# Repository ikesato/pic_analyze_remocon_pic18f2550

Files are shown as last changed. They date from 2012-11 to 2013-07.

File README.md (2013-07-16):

概要
====
家庭用リモコン信号を受信しコードを解析する。  
また解析したコードを送信し解析したコードのテストを可能とする。  

- マイコン : PIC18F2550
- USB接続 (CDC クラスを使用)
- CDC Basic Demo をベースに赤外線LEDの送受信し、データをシリアル通信で送受信
- 赤外通信 38KHz
- 解析できるコードは家電協フォーマット、ソニーフォーマット
- 受信と解析  
 リモコン -> 赤外線受光部 -> マイコン -> PCでコードを解析
- 送信  
 PC -> マイコン -> 赤外LEDで送信
- フリスクケースに収まるサイズで作成

回路図
=====
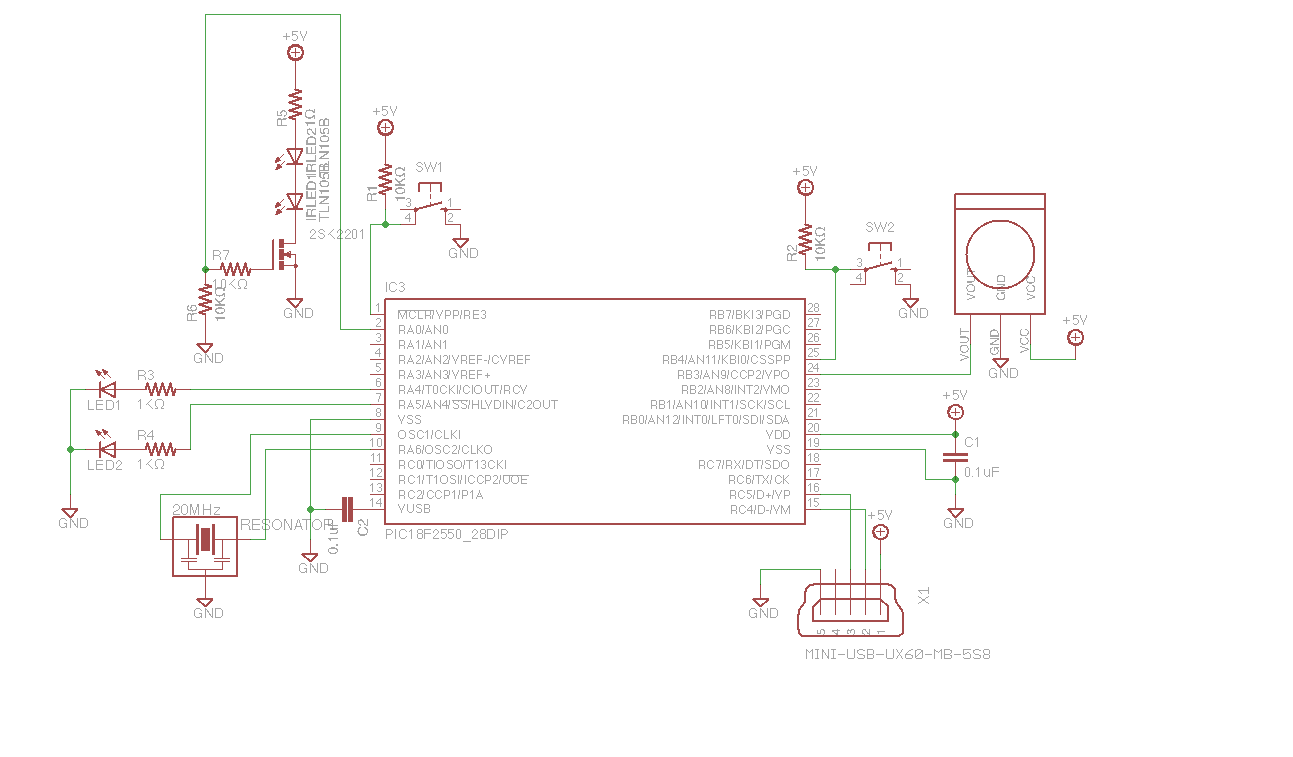
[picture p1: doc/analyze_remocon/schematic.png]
回路図


配線
====
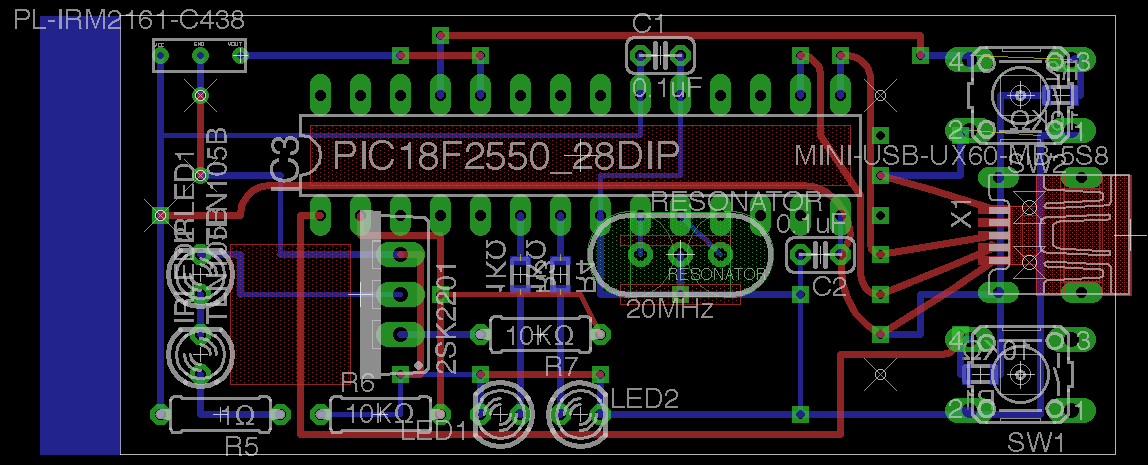
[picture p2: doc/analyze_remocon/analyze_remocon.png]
配線


部品
====
- LED x 2
- 赤外線LED x 2
 型番 : TLN105B
- 赤外線受光モジュール  
 型番 : PL-IRM2161-C438
- FET  
 型番 : 2SK2201
- 水晶振動子 20MHz
- マイコン : PIC18F2550 DIP 28ピン
- USBコネクタ変換基板  
 型番 : サンハヤト CK-37  
 ケースに収めるため一部カット加工
- スイッチ （モーメンタリ） x 2
- コンデンサ 0.1uF x 2
- 抵抗  
 1KΩ  (チップ抵抗) x 2  
 1Ω  x 1  
 10KΩ  x 2  

使用方法
========

1. 接続  
 マイコン部とPCをUSBケーブルで接続する。  
 USBから電源供給をおこなう。  
2. PCでリモコン解析用ツールを起動する  
 `$ ruby serial/ranalyzer.rb /dev/tty.usbXXXXXX`  
 /dev/tty.usbXXXXXX にはシリアルポートデバイスを指定
 Mac の場合は ls /dev/tty.usb* に存在するデバイス
3. 家庭用リモコンをマイコン部に向けて何かボタンを押す
4. 改正気結果がコンソールに表示
5. 解析結果の行をコピー＆ペーストで、そのコードの送信テストが可能
6. ボタンの説明
 - SW1  
  リセットボタン
 - SW2  
  最後に受信または送信したリモコンコードを送信。  
  ２秒長押しで赤外線受信の ON/OFF を切り替え。（テレビが付いている場合、テレビの映像に反応してしまうような場合に赤外線受信をOFFにして使うと便利です）  
 - SW2 を先に押した状態にし、SW1 を押すとファームウェア書き換えモードになる。  
  HIDBootloader などでファームを書き換える事が可能。  

ディレクトリ構成
================

- Firmware ディレクトリ  
 ファームウェアの全ソースコード
- inf ディレクトリ  
 Windows の場合の USBドライバ （動作未確認）
- serial ディレクトリ  
 リモコン解析ツール  
 ruby 製です。1.9.x で作成してますが、たぶん 1.8.x , 2.x でも動くはず。  
 - 必要な gem  
  serialport, optparse
- hex ファイル  
 Firmware/MPLAB.X/dist/PICDEM_FSUSB/production/MPLAB.X.production.hex

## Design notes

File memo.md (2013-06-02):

CPU クロックは 48MHz

38KHz
-----
38KHz == 26.3157894736842[us] => (デューティー比 1/3 hi:lo=1:2)
48MHz == 0.020833333333333[us/clock] == 0.083333333[us/cycle]

HI または LO のdelay を計算
26.3157894736842 / 0.083333333 = 315.78947368421[cycle]

デューティ比 33% なので
HI:105.263157894737[cycle] == 8.77192982456142[us]
LO:210.526315789474[cycle] == 17.5438596491228[us]

デューティ比 50% の場合 315.78947368421 / 2 = 157.894736842105[cycle]
HI:157.894736842105[cycle] == 13.1578947368421[us]
LO:157.894736842105[cycle] == 13.1578947368421[us]

Mac で 直接USBシリアル通信する方法
----------------------------------
上の ranalyzer.rb が使えないとき、直接シリアル通信して
デバッグする方法

- cu を使う方法
 sudo cu -l /dev/tty.usbmodemfa131 -s 19200

- screen を使う方法
 screen -c /dev/null /dev/tty.usbmodemfa131 119200

format
------
家電協 T:0.425ms 1T=79.69 Leader(H8T  L4T) 0:(H1T L1T) 1:(H1T L3T)
NEC    T:0.560ms 1T=105   Leader(H16T L8T) 0:(H1T L1T) 1:(H1T L3T) bitlen=32,42
SONY   T:0.600ms 1T=112.5 Leader(H4T  L1T) 0:(H1T L1T) 1:(H2T L1T) bitlen=12,15,20
JVC    T:0.517ms 1T=97    Leader(H16T L8T) 0:(H1T L1T) 1:(H1T L3T) bitlen=16,32

timer0
------
PIC タイマー0 について
プリスケーラ 1/64 を使用。
1:64 48MHz/4=12MHz => 0.08333[us/cycle] => *64 => 5.33333us
タイマー単位の 1 は 5.33333[us]

リモコンデータ
--------------
- Aiwa リモコン => NECフォーマット  
    NEC T=0.559[ms] 42bit [7b 80 f0 03 fc 03, REP8T] # 電源  
    NEC T=0.561[ms] 42bit [7b 80 f0 03 fc 03, REP8T, REP8T, REP8T, REP8T] # 電源長押  
    NEC T=0.558[ms] 42bit [7b 80 f0 3b c4 03, REP8T] # テレビ/ビデオ  
    NEC T=0.558[ms] 42bit [7b 80 f0 0b f5 02, REP8T] # オフタイマー  
    NEC T=0.559[ms] 42bit [7b 80 f0 0f f1 02, REP8T] # おやすみタイマー  
    NEC T=0.559[ms] 42bit [7b 80 f0 f3 0d 02, REP8T] # ゲーム  
    NEC T=0.559[ms] 42bit [7b 80 f0 07 f8 03, REP8T] # 1ch  
    NEC T=0.559[ms] 42bit [7b 80 f0 0b f4 03, REP8T] # 2ch  
    NEC T=0.559[ms] 42bit [7b 80 f0 0f f0 03, REP8T] # 3ch  
    NEC T=0.559[ms] 42bit [7b 80 f0 13 ec 03, REP8T] # 4ch  
    NEC T=0.559[ms] 42bit [7b 80 f0 17 e8 03, REP8T] # 5ch  
    NEC T=0.560[ms] 42bit [7b 80 f0 1b e4 03, REP8T] # 6ch  
    NEC T=0.560[ms] 42bit [7b 80 f0 1f e0 03, REP8T] # 7ch  
    NEC T=0.561[ms] 42bit [7b 80 f0 23 dc 03, REP8T] # 8ch  
    NEC T=0.559[ms] 42bit [7b 80 f0 27 d8 03, REP8T] # 9ch  
    NEC T=0.559[ms] 42bit [7b 80 f0 2b d4 03, REP8T] # 10ch  
    NEC T=0.560[ms] 42bit [7b 80 f0 2f d0 03, REP8T] # 11ch  
    NEC T=0.559[ms] 42bit [7b 80 f0 33 cc 03, REP8T] # 12ch  
    NEC T=0.560[ms] 42bit [7b 80 f0 e7 1a 01, REP8T] # ミッドナイトシアター  
    NEC T=0.560[ms] 42bit [7b 80 f0 4f b0 03, REP8T] # 音多モード  
    NEC T=0.559[ms] 42bit [7b 80 f0 8f 71 02, REP8T] # ピクチャーメニュー  
    NEC T=0.559[ms] 42bit [7b 80 f0 3f c1 02, REP8T] # 表示切り替え  
    NEC T=0.559[ms] 42bit [7b 80 f0 2b d5 02, REP8T] # ミュート  
    NEC T=0.560[ms] 42bit [7b 80 f0 6f 90 03, REP8T] # メニュー  
    NEC T=0.559[ms] 42bit [7b 80 f0 ab 55 02, REP8T] # 決定  
    NEC T=0.559[ms] 42bit [7b 80 f0 03 fd 02, REP8T] # チャンネルup  
    NEC T=0.559[ms] 42bit [7b 80 f0 07 f9 02, REP8T] # チャンネルdown  
    NEC T=0.559[ms] 42bit [7b 80 f0 63 9c 03, REP8T] # 音量up  
    NEC T=0.559[ms] 42bit [7b 80 f0 67 98 03, REP8T] # 音量down

- Victor テレビリモコン => JVCフォーマット  
    JVC T=0.516[ms] CYCLE=44.5[ms] 16bit [03 17, 03 17] # 電源  
    JVC T=0.517[ms] CYCLE=44.6[ms] 16bit [03 00, 03 00] # 音声切換  
    JVC T=0.517[ms] CYCLE=44.7[ms] 16bit [03 03, 03 03] # オフタイマー  
    JVC T=0.516[ms] CYCLE=44.6[ms] 16bit [03 10, 03 10] # アナログ  
    JVC T=0.517[ms] CYCLE=44.7[ms] 16bit [0f 15, 0f 15] # デジタル  
    JVC T=0.516[ms] CYCLE=44.6[ms] 16bit [03 0c, 03 0c] # BS  
    JVC T=0.517[ms] CYCLE=44.7[ms] 16bit [0f 14, 0f 14] # CS  
    JVC T=0.515[ms] CYCLE=44.6[ms] 16bit [03 21, 03 21] # 1ch  
    JVC T=0.516[ms] CYCLE=44.6[ms] 16bit [03 22, 03 22] # 2ch  
    JVC T=0.516[ms] CYCLE=44.6[ms] 16bit [03 23, 03 23] # 3ch  
    JVC T=0.515[ms] CYCLE=44.6[ms] 16bit [03 24, 03 24] # 4ch  
    JVC T=0.516[ms] CYCLE=44.6[ms] 16bit [03 25, 03 25] # 5ch  
    JVC T=0.515[ms] CYCLE=44.6[ms] 16bit [03 26, 03 26] # 6ch  
    JVC T=0.517[ms] CYCLE=44.6[ms] 16bit [03 27, 03 27] # 7ch  
    JVC T=0.515[ms] CYCLE=44.6[ms] 16bit [03 28, 03 28] # 8ch  
    JVC T=0.516[ms] CYCLE=44.6[ms] 16bit [03 29, 03 29] # 9ch  
    JVC T=0.517[ms] CYCLE=44.6[ms] 16bit [03 2a, 03 2a] # 10ch  
    JVC T=0.516[ms] CYCLE=44.5[ms] 16bit [03 2b, 03 2b] # 11ch  
    JVC T=0.517[ms] CYCLE=44.6[ms] 16bit [03 2c, 03 2c] # 12ch  
    JVC T=0.518[ms] CYCLE=44.6[ms] 16bit [03 1e, 03 1e] # 音量up  
    JVC T=0.516[ms] CYCLE=44.6[ms] 16bit [03 1f, 03 1f] # 音量down  
    JVC T=0.516[ms] CYCLE=44.6[ms] 16bit [03 1e, 03 1e, 03 1e, 03 1e, 03 1e, 03 1e, 03 1e, 03 1e, 03 1e] # 音量up長押し  
    JVC T=0.517[ms] CYCLE=44.6[ms] 16bit [03 19, 03 19] # chanel up  
    JVC T=0.516[ms] CYCLE=44.6[ms] 16bit [03 18, 03 18] # chanel down  
    JVC T=0.517[ms] CYCLE=44.6[ms] 16bit [0f 7d, 0f 7d] # 番組表  
    JVC T=0.517[ms] CYCLE=44.6[ms] 16bit [03 e6, 03 e6] # 戻る  
    JVC T=0.517[ms] CYCLE=44.7[ms] 16bit [03 7a, 03 7a] # ホーム/メニュー  
    JVC T=0.516[ms] CYCLE=44.7[ms] 16bit [03 04, 03 04] # 画面表示  
    JVC T=0.517[ms] CYCLE=44.7[ms] 16bit [03 7c, 03 7c] # 上  
    JVC T=0.517[ms] CYCLE=44.7[ms] 16bit [03 5a, 03 5a] # 右  
    JVC T=0.517[ms] CYCLE=44.5[ms] 16bit [03 ec, 03 ec] # 下  
    JVC T=0.517[ms] CYCLE=44.6[ms] 16bit [03 5b, 03 5b] # 左  
    JVC T=0.515[ms] CYCLE=44.5[ms] 16bit [03 0a, 03 0a] # 決定  
    JVC T=0.516[ms] CYCLE=44.6[ms] 16bit [03 13, 03 13] # 入力切り替え  
    JVC T=0.516[ms] CYCLE=44.6[ms] 16bit [03 1c, 03 1c] # ミュート  
    JVC T=0.516[ms] CYCLE=44.6[ms] 16bit [0f 1c, 0f 1c] # 10キー  
    JVC T=0.516[ms] CYCLE=44.6[ms] 16bit [23 a0, 23 a0] # d連動データ  
    JVC T=0.517[ms] CYCLE=44.6[ms] 16bit [23 c3, 23 c3] # 青  
    JVC T=0.516[ms] CYCLE=44.6[ms] 16bit [23 c0, 23 c0] # 赤  
    JVC T=0.516[ms] CYCLE=44.6[ms] 16bit [23 c1, 23 c1] # 緑  
    JVC T=0.516[ms] CYCLE=44.7[ms] 16bit [23 c2, 23 c2] # 黃  
    JVC T=0.517[ms] CYCLE=44.7[ms] 16bit [03 93, 03 93] # ワイド切換  
    JVC T=0.517[ms] CYCLE=44.6[ms] 16bit [0f 7c, 0f 7c] # 番組説明  

- SONY すごろく => SONY フォーマット  
    SONY T=0.586[ms] 20bit [15 ad 0f, 15 ad 0f, 15 ad 0f] # 電源  
    SONY T=0.586[ms] 20bit [16 ad 0f, 16 ad 0f, 16 ad 0f] # 開閉  
    SONY T=0.587[ms] 20bit [64 ad 0f, 64 ad 0f, 64 ad 0f] # 音声切換  
    SONY T=0.587[ms] 20bit [00 ad 0f, 00 ad 0f, 00 ad 0f] # 1ch  
    SONY T=0.588[ms] 20bit [01 ad 0f, 01 ad 0f, 01 ad 0f] # 2ch  
    SONY T=0.587[ms] 20bit [02 ad 0f, 02 ad 0f, 02 ad 0f] # 3ch  
    SONY T=0.587[ms] 20bit [03 ad 0f, 03 ad 0f, 03 ad 0f] # 4ch  
    SONY T=0.586[ms] 20bit [04 ad 0f, 04 ad 0f, 04 ad 0f] # 5ch  
    SONY T=0.587[ms] 20bit [05 ad 0f, 05 ad 0f, 05 ad 0f] # 6ch  
    SONY T=0.587[ms] 20bit [06 ad 0f, 06 ad 0f, 06 ad 0f] # 7ch  
    SONY T=0.588[ms] 20bit [07 ad 0f, 07 ad 0f, 07 ad 0f] # 8ch  
    SONY T=0.588[ms] 20bit [08 ad 0f, 08 ad 0f, 08 ad 0f] # 9ch  
    SONY T=0.586[ms] 20bit [09 ad 0f, 09 ad 0f, 09 ad 0f] # 10ch  
    SONY T=0.588[ms] 20bit [0a ad 0f, 0a ad 0f, 0a ad 0f] # 11ch  
    SONY T=0.586[ms] 20bit [0d ad 0f, 0d ad 0f, 0d ad 0f] # 12ch  
    SONY T=0.586[ms] 20bit [6c bd 00, 6c bd 00, 6c bd 00] # アナログ  
    SONY T=0.586[ms] 20bit [6b bd 00, 6b bd 00, 6b bd 00] # デジタル  
    SONY T=0.588[ms] 20bit [6a bd 00, 6a bd 00, 6a bd 00] # BS  
    SONY T=0.587[ms] 20bit [6e bd 00, 6e bd 00, 6e bd 00] # CS  
    SONY T=0.588[ms] 20bit [61 bd 00, 61 bd 00, 61 bd 00] # 10キー  
    SONY T=0.587[ms] 20bit [13 ad 0f, 13 ad 0f, 13 ad 0f] # channel up  
    SONY T=0.587[ms] 20bit [14 ad 0f, 14 ad 0f, 14 ad 0f] # channel down  
    SONY T=0.587[ms] 20bit [13 ad 0f, 13 ad 0f, 13 ad 0f, 13 ad 0f, 13 ad 0f, 13 ad 0f, 13 ad 0f, 13 ad 0f, 13 ad 0f] # channel up 長押し  
    SONY T=0.586[ms] 20bit [50 bd 00, 50 bd 00, 50 bd 00] # HDD/BD  
    SONY T=0.588[ms] 20bit [62 bd 00, 62 bd 00, 62 bd 00] # d連動データ  
    SONY T=0.587[ms] 20bit [66 bd 00, 66 bd 00, 66 bd 00] # 青  
    SONY T=0.586[ms] 20bit [67 bd 00, 67 bd 00, 67 bd 00] # 赤  
    SONY T=0.588[ms] 20bit [68 bd 00, 68 bd 00, 68 bd 00] # 緑  
    SONY T=0.587[ms] 20bit [69 bd 00, 69 bd 00, 69 bd 00] # 黃  
    SONY T=0.587[ms] 20bit [1b ad 0f, 1b ad 0f, 1b ad 0f] # 3d  
    SONY T=0.587[ms] 20bit [1a ad 0f, 1a ad 0f, 1a ad 0f] # アクトビラ  
    SONY T=0.586[ms] 20bit [16 bd 00, 16 bd 00, 16 bd 00] # 番組表  
    SONY T=0.588[ms] 20bit [0e ad 0f, 0e ad 0f, 0e ad 0f] # 戻る  
    SONY T=0.586[ms] 20bit [53 ad 0f, 53 ad 0f, 53 ad 0f] # ホーム/メニュー  
    SONY T=0.588[ms] 20bit [17 bd 00, 17 bd 00, 17 bd 00] # オプション  
    SONY T=0.586[ms] 20bit [54 ad 0f, 54 ad 0f, 54 ad 0f] # 画面表示  
    SONY T=0.588[ms] 20bit [5a ad 0f, 5a ad 0f, 5a ad 0f] # リンクメニュー  
    SONY T=0.588[ms] 20bit [79 ad 0f, 79 ad 0f, 79 ad 0f] # 上  
    SONY T=0.587[ms] 20bit [7c ad 0f, 7c ad 0f, 7c ad 0f] # 右  
    SONY T=0.587[ms] 20bit [7a ad 0f, 7a ad 0f, 7a ad 0f] # 下  
    SONY T=0.588[ms] 20bit [7b ad 0f, 7b ad 0f, 7b ad 0f] # 左  
    SONY T=0.588[ms] 20bit [0b ad 0f, 0b ad 0f, 0b ad 0f] # 決定  
    SONY T=0.586[ms] 20bit [18 bd 00, 18 bd 00, 18 bd 00] # シアター  
    SONY T=0.587[ms] 20bit [10 bd 00, 10 bd 00, 10 bd 00] # 録画リスト  
    SONY T=0.588[ms] 20bit [30 ad 0f, 30 ad 0f, 30 ad 0f] # |<< 前  
    SONY T=0.588[ms] 20bit [5c ad 0f, 5c ad 0f, 5c ad 0f] # <-.  
    SONY T=0.587[ms] 20bit [14 bd 00, 14 bd 00, 14 bd 00] # .->  
    SONY T=0.588[ms] 20bit [31 ad 0f, 31 ad 0f, 31 ad 0f] # >>| 次  
    SONY T=0.588[ms] 20bit [33 ad 0f, 33 ad 0f, 33 ad 0f] # << 巻き戻し  
    SONY T=0.587[ms] 20bit [32 ad 0f, 32 ad 0f, 32 ad 0f] # >  play  
    SONY T=0.588[ms] 20bit [34 ad 0f, 34 ad 0f, 34 ad 0f] # >> 早送り  
    SONY T=0.587[ms] 20bit [19 ad 0f, 19 ad 0f, 19 ad 0f] # 録画  
    SONY T=0.587[ms] 20bit [39 ad 0f, 39 ad 0f, 39 ad 0f] # || 一時停止  
    SONY T=0.586[ms] 20bit [38 ad 0f, 38 ad 0f, 38 ad 0f] # ■ 停止  
    SONY T=0.588[ms] 20bit [65 ad 0f, 65 ad 0f, 65 ad 0f] # ワイド切換  
    SONY T=0.587[ms] 20bit [63 ad 0f, 63 ad 0f, 63 ad 0f] # 字幕  
    SONY T=0.588[ms] 20bit [12 ad 0f, 12 ad 0f, 12 ad 0f] # ２画面表示  
    SONY T=0.588[ms] 20bit [15 bd 00, 15 bd 00, 15 bd 00] # 番組説明  

* ダイキンエアコン電源ボタン  
    DAIKIN T=0.425[ms] [11 da 27 00 c5 00 20 f7, 11 da 27 00 42 00 00 54, 11 da 27 00 00 48 3a 00 a0 00 00 06 60 00 00 c1 80 00 db] # 電源OFF (運転中, 29度, 暖房, 風量自動, フィルター掃除)  
    DAIKIN T=0.425[ms] [11 da 27 00 c5 00 20 f7, 11 da 27 00 42 00 00 54, 11 da 27 00 00 49 3a 00 a0 00 00 06 60 00 00 c1 80 00 dc] # 電源ON  (運転中, 29度, 暖房, 風量自動, フィルター掃除)  
    DAIKIN T=0.425[ms] [11 da 27 00 c5 00 20 f7, 11 da 27 00 42 00 00 54, 11 da 27 00 00 49 3a 00 a0 00 3c 00 60 00 00 c1 a0 00 32] # 快眠1回 (運転中, 29度, 暖房, 風量自動, フィルター掃除, 快眠1時間後)  
    DAIKIN T=0.425[ms] [11 da 27 00 c5 00 20 f7, 11 da 27 00 42 00 00 54, 11 da 27 00 00 49 3a 00 a0 00 78 00 60 00 00 c1 a0 00 6e] # 快眠2回 (運転中, 29度, 暖房, 風量自動, フィルター掃除, 快眠2時間後)  
    DAIKIN T=0.425[ms] [11 da 27 00 c5 00 20 f7, 11 da 27 00 42 00 00 54, 11 da 27 00 00 49 3a 00 a0 00 00 06 60 00 00 c1 80 00 dc] # 快眠N回で解除 (運転中, 29度, 暖房, 風量自動, フィルター掃除) (上の電源ONと同じ)  
    DAIKIN T=0.425[ms] [11 da 27 00 c5 00 20 f7, 11 da 27 00 42 00 00 54, 11 da 27 00 00 49 3c 00 a0 00 00 06 60 00 00 c1 80 00 de] # 温度上  (運転中, 30度, 暖房, 風量自動, フィルター掃除)  

    DAIKIN T=0.425[ms] [11 da 27 00 c5 00 20 f7, 11 da 27 00 42 00 00 54, 11 da 27 00 00 49 3c 00 a0 00 00 06 60 00 00 c1 80 00 de] # 運転中, 30度, 暖房, 風量自動, フィルター掃除  
    DAIKIN T=0.425[ms] [11 da 27 00 c5 00 20 f7, 11 da 27 00 42 00 00 54, 11 da 27 00 00 69 32 00 a0 00 00 06 60 00 00 c1 80 00 f4] # 運転中, 30度, 送風, 風量自動, フィルター掃除  
    DAIKIN T=0.425[ms] [11 da 27 00 c5 00 20 f7, 11 da 27 00 42 00 00 54, 11 da 27 00 00 39 34 00 a0 00 00 06 60 00 00 c1 80 00 c6] # 運転中, 26度, 冷房, 風量自動, フィルター掃除  

    DAIKIN T=0.425[ms] [11 da 27 00 c5 00 20 f7, 11 da 27 00 42 00 00 54, 11 da 27 00 00 29 c0 80 a0 00 00 06 60 00 00 c1 80 00 c2] # 運転中, 30度(非表示), ドライ, 風量自動, フィルター掃除  

    DAIKIN T=0.425[ms] [11 da 27 00 c5 00 20 f7, 11 da 27 00 42 00 00 54, 11 da 27 00 00 49 32 00 af 00 00 06 60 00 00 c1 80 00 e3] # 運転中, 25度, 暖房, 風量自動, フィルター掃除 

    DAIKIN T=0.425[ms] [11 da 27 00 84 14 00 aa] # フィルター掃除ボタン (電源offのみ押せる)
    DAIKIN T=0.425[ms] [11 da 27 00 84 13 00 a9] # リセット(2秒長押しでないと効かない)
    DAIKIN T=0.425[ms] [11 da 27 00 84 0c 00 a2] # 内部クリーン(2秒長押しでないと効かない) (電源off時)
    DAIKIN T=0.425[ms] [11 da 27 00 c5 00 28 ff, 11 da 27 00 42 00 00 54, 11 da 27 00 00 49 34 00 a0 00 00 06 60 00 00 c1 80 00 d6] # 内部クリーン (運転中)

    DAIKIN T=0.425[ms] [11 da 27 00 c5 00 28 ff, 11 da 27 00 42 00 00 54, 11 da 27 00 00 48 34 00 a0 00 00 06 60 00 00 c1 80 00 d5]

    DAIKIN T=0.425[ms] [11 da 27 00 c5 00 28 ff, 11 da 27 00 42 00 00 54, 11 da 27 00 00 49 36 00 a0 00 00 06 60 00 00 c1 80 00 d8] # 運転中にこれを送信したら内部クリーンランプが点灯状態となった

    DAIKIN T=0.425[ms] [11 da 27 00 c5 00 20 f7, 11 da 27 00 42 00 00 54, 11 da 27 00 00 38 32 00 a0 00 00 06 60 08 00 c1 80 00 cb] # 健康冷房
    DAIKIN T=0.425[ms] [11 da 27 00 c5 00 30 07, 11 da 27 00 42 00 00 54, 11 da 27 00 00 38 32 00 a0 00 00 06 60 08 00 c1 80 00 cb] # 健康冷房, 風ナイス

----------------    0  1  2  3  4  5  6  7  8  9  10 11 12 13 14 15 16 17               11.2
                                                                                          11.1-10.2 10.0,1
DAIKIN T=0.425[ms] [11 da 27 00 00 4b 34 00 a0 00 3c 00 60 00 00 c1 80 00 0e] #  1h後入 0 0000 1111 00
DAIKIN T=0.425[ms] [11 da 27 00 00 4b 34 00 a0 00 78 00 60 00 00 c1 80 00 4a] #  2h後入 0 0001 1110 00
DAIKIN T=0.425[ms] [11 da 27 00 00 4b 34 00 a0 00 b4 00 60 00 00 c1 80 00 86] #  3h後入 0 0010 1101 00
DAIKIN T=0.425[ms] [11 da 27 00 00 4b 34 00 a0 00 f0 00 60 00 00 c1 80 00 c2] #  4h後入 0 0011 1100 00
DAIKIN T=0.425[ms] [11 da 27 00 00 4b 34 00 a0 00 2c 01 60 00 00 c1 80 00 ff] #  5h後入 0 0100 1011 00
DAIKIN T=0.425[ms] [11 da 27 00 00 4b 34 00 a0 00 68 01 60 00 00 c1 80 00 3b] #  6h後入 0 0101 1010 00
DAIKIN T=0.425[ms] [11 da 27 00 00 4b 34 00 a0 00 a4 01 60 00 00 c1 80 00 77] #  7h後入 0 0110 1001 00
DAIKIN T=0.425[ms] [11 da 27 00 00 4b 34 00 a0 00 e0 01 60 00 00 c1 80 00 b3] #  8h後入 0 0111 1000 00
DAIKIN T=0.425[ms] [11 da 27 00 00 4b 34 00 a0 00 1c 02 60 00 00 c1 80 00 f0] #  9h後入 0 1000 0111 00
DAIKIN T=0.425[ms] [11 da 27 00 00 4b 34 00 a0 00 58 02 60 00 00 c1 80 00 2c] # 10h後入 0 1001 0110 00
DAIKIN T=0.425[ms] [11 da 27 00 00 4b 34 00 a0 00 94 02 60 00 00 c1 80 00 68] # 11h後入 0 1010 0101 00
DAIKIN T=0.424[ms] [11 da 27 00 00 4b 34 00 a0 00 d0 02 60 00 00 c1 80 00 a4] # 12h後入 0 1011 0100 00
DAIKIN T=0.425[ms] [11 da 27 00 00 49 34 00 a0 00 00 06 60 00 00 c1 80 00 d6] #         1 1000 0000 00

----------------    0  1  2  3  4  5  6  7  8  9  10 11 12 13 14 15 16 17               12.6
DAIKIN T=0.425[ms] [11 da 27 00 00 49 34 00 a0 00 00 06 60 00 00 c1 80 00 d6] #           12.5-11.6 11.4,5
DAIKIN T=0.425[ms] [11 da 27 00 00 4d 34 00 a0 00 00 c6 03 00 00 c1 80 00 3d] #  1h後切 0 0000 1111 00
DAIKIN T=0.425[ms] [11 da 27 00 00 4d 34 00 a0 00 00 86 07 00 00 c1 80 00 01] #  2h後切 0 0001 1110 00
DAIKIN T=0.425[ms] [11 da 27 00 00 4d 34 00 a0 00 00 46 0b 00 00 c1 80 00 c5] #  3h後切 0 0010 1101 00
DAIKIN T=0.425[ms] [11 da 27 00 00 4d 34 00 a0 00 00 06 0f 00 00 c1 80 00 89] #  4h後切 0 0011 1100 00
DAIKIN T=0.425[ms] [11 da 27 00 00 4d 34 00 a0 00 00 c6 12 00 00 c1 80 00 4c] #  5h後切 0 0100 1011 00
DAIKIN T=0.425[ms] [11 da 27 00 00 4d 34 00 a0 00 00 86 16 00 00 c1 80 00 10] #  6h後切 0 0101 1010 00
DAIKIN T=0.425[ms] [11 da 27 00 00 4d 34 00 a0 00 00 46 1a 00 00 c1 80 00 d4] #  7h後切 0 0110 1001 00
DAIKIN T=0.425[ms] [11 da 27 00 00 4d 34 00 a0 00 00 06 1e 00 00 c1 80 00 98] #  8h後切 0 0111 1000 00
DAIKIN T=0.425[ms] [11 da 27 00 00 4d 34 00 a0 00 00 c6 21 00 00 c1 80 00 5b] #  9h後切 0 1000 0111 00
DAIKIN T=0.425[ms] [11 da 27 00 00 49 34 00 a0 00 00 06 60 00 00 c1 80 00 d6] #         1 1000 0000 00

----------------    0  1  2  3  4  5  6  7  8  9  10 11 12 13 14 15 16 17
DAIKIN T=0.425[ms] [11 da 27 00 00 4f 34 00 a0 00 3c c0 03 00 00 c1 80 00 75] #  1h後入+1h後切
DAIKIN T=0.425[ms] [11 da 27 00 00 4f 34 00 a0 00 78 80 07 00 00 c1 80 00 75] #  2h後入+2h後切

# なんか不明なフォーマット
DAIKIN T=0.425[ms] [11 da 27 00 c5 00 28 ff, 11 da 27 00 42 00 00 54, 11 da 27 00 00 4e 34 00 a0 00 3a 70 07 00 00 c1 80 00 26] # 1h後入+2h後切

DAIKIN T=0.426[ms] [11 da 27 00 c5 00 28 ff, 11 da 27 00 42 00 00 54, 11 da 27 00 00 4f 34 00 a0 00 e0 f1 0e 00 00 c1 80 00 55] # 8h後入+4h後切, 運転中, 暖房, 26度, 風量自動, フィルター掃除
DAIKIN T=0.425[ms] [11 da 27 00 c5 00 28 ff, 11 da 27 00 42 00 00 54, 11 da 27 00 00 4f 34 00 a0 00 df c1 12 00 00 c1 80 00 28] # 8h後入+5h後切, 運転中, 暖房, 26度, 風量自動, フィルター掃除
DAIKIN T=0.425[ms] [11 da 27 00 c5 00 28 ff, 11 da 27 00 42 00 00 54, 11 da 27 00 00 4f 34 00 a0 00 de 81 16 00 00 c1 80 00 eb] # 8h後入+6h後切, 運転中, 暖房, 26度, 風量自動, フィルター掃除
DAIKIN T=0.425[ms] [11 da 27 00 c5 00 28 ff, 11 da 27 00 42 00 00 54, 11 da 27 00 00 4e 34 00 a0 00 3c f0 14 00 00 c1 80 00 b5] # 1h後入+6h後切, 運転中, 暖房, 26度, 風量自動, フィルター掃除

タイマー予約した後数分たった時？
                                                   切                入
2h後切+1h後入? : 00111010 01110000 00000111 => 00 0001 1101 11 0 0 0000 1110 10
4h後切+8h後入  : 11100000 11110001 00001110 => 00 0011 1011 11 0 0 0111 1000 00
5h後切+8h後入  : 11011111 11000001 00010010 => 00 0100 1011 00 0 0 0111 0111 11
6h後切+8h後入  : 11011110 10000001 00010110 => 00 0101 1010 00 0 0 0111 0111 10
6h後切+1h後入  : 00111100 11110000 00010100 => 00 0101 0011 11 0 0 0000 1111 00

2h後切+2h後入  : 00111100 11000000 00000011 => 00 0000 1111 00 0 0 0000 1111 00
2h後切+2h後入  : 01111000 10000000 00000111 => 00 0001 1110 00 0 0 0001 1110 00

----------------    0  1  2  3  4  5  6  7  8  9  10 11 12 13 14 15 16 17      12.6 12.5-11.6 11.4,5
DAIKIN T=0.425[ms] [11 da 27 00 00 4e 34 00 a0 00 3a 70 07 00 00 c1 80 00 26] #   0 0001 1101 11  タイマー切
                                                                               11.2 11.1-10.2 10.0,1
DAIKIN T=0.425[ms] [11 da 27 00 00 4e 34 00 a0 00 3a 70 07 00 00 c1 80 00 26] #   0 0000 1110 10  タイマー入
byte10-12 : [3a 70 07]
            "02 30 00"

    * フォーマット  
     body0
    11 da 27 00 c5 00 20 f7, # body0
    11 da 27 00 42 00 00 54, # body1 固定?
    11 da 27 00 00 29 c0 80 a0 00 00 06 60 00 00 c1 80 00 c2 # body2

    * チェックサム
    body0,1,2 の最終バイトは必ずチェックサムになる

    ** body0
      byte
      0-3 : 11 da 27 00 固定
      4   : c5 通常モード(body1,2あり)
            84 特殊モード(body1,2なし)
      5   : 通常モードは 00 固定
            特殊モード
              13 : リセット
              14 : フィルター掃除
      6   : 特殊モードは 00 固定
            通常モード
              bit0-2 => B'000 固定
              bit3   => 内部クリーン 0:off 1:on
              bit4   => 風ないス 0:off 1:on
              bit5-7 => B'001 固定
      7   : byte0-6のチェックサム  

    ** body1
      byte
      0-6 : 11 da 27 00 42 00 00 固定?  
      7   : byte0-6のチェックサム  

    ** body2
    bitlength : 19*8 [bit]  
    11 da 27 00 00 29 c0 80 a0 00 00 06 60 00 00 c1 80 00 c2  # データ例  
    0  1  2  3  4 |5  6  7  8  9  10 11 12 13 14 15 16 17|18  # <- position  

    byte
      0-4  : 固定 11 da 27 00 00  
      5    : bit0 => 1:電源on 0:電源off
             bit1 => タイマー入 0:on 1:off
             bit2 => タイマー切 0:on 1:off
             bit3 => 1固定
             bit4-6 => 0:標準(自動) 1:? 2:標準(ドライ) 3:冷房 4:暖房 5:? 6:送風 7:?
             bit7 => 0固定?
      6,7  : 温度
               標準(ドライ) / 標準(自動) の場合
                 bit0 => 0固定?
                 bit1-4 => 温度
                             B'0000:+-0
                             B'0001:+1 B'0010:+2 B'0011:+3 B'0100:+4 B'0101:+5
                             B'1111:-1 B'1110:-2 B'1101:-3 B'1100:-4 B'1011:-5
                 bit5-7 => B'110 固定
                 bit8-15 => 80h 固定
               冷房の場合
                 bit0 => 0固定?
                 bit1-6 => 温度 (18-32度)
                             B'010010:18 B'010011:19 ... B'010111:23 B'011000:24 ... B'011111:31 B'100000:32
                 bit7 => 0 固定
                 bit8-15 => 00h 固定
               暖房の場合
                 bit0 => 0固定?
                 bit1-6 => 温度 (14-30度)
                             B'001110:14 ... B'001111:15 ... B'010111:23 ... B'011110:30
                 bit7 => 0 固定
                 bit8-15 => 00h 固定
               送風の場合
                 bit0-7 => 32h 固定
                 bit8-15 => 00h 固定
      8    : bit0-3 => 風向き 0h:オフ fh:オン
             bit4-7 => B'0011:風量1 B'0100:風量2 ... B'0111:風量5 B'1010:風量自動 B'1011:しずか
      9    : 00h 固定?
      10.0-10.1 : (2bit) B'00 固定
      10.2-10.5 : (4bit)
             タイマー入on  の場合 N 時間後とすると 0-N
             タイマー入off の場合 B'0000
      10.6-11.1 : (4bit)
             タイマー入on  の場合 N 時間後とすると N-1
             タイマー入off の場合 B'1000
      11.2 : タイマー入on  の場合 0
             タイマー入off の場合 1
      11.3-11.5 : (3bit)
             B'000 固定

      11.6-12.1 : (4bit)
             タイマー切on  の場合 N 時間後とすると 0-N
             タイマー切off の場合 B'0000
      12.2-12.5 : (4bit)
             タイマー切on  の場合 N 時間後とすると N-1
             タイマー切off の場合 B'1000
      12.6 : タイマー切on  の場合 0
             タイマー切off の場合 1
      12.7 : 0 固定
      13   : 健康冷房 08h:オン 00h:オフ
             * 冷房時のみ押せて、強制的に風量自動になる
             * オンの場合、風量、温度が押せない
             * オンの場合、風量は強制的に風量自動 byte8.4-7 が B'1010 となる
               もう一度押してオフにした場合、風量 byte8.4-7 は健康冷房の前の状態に戻る
             * オンの場合、温度は押せないが最後に設定した温度が byte6.1-6 に残る
      14-17: 00 c1 80 00 固定
      18  : 前18バイトのチェックサム  

    ** 快眠:強制的に標準(自動) になる

    ** フィルター掃除ボタンは電源OFFしか押せない

    ** 内部クリーンについて
     運転中に内部クリーンを２秒長押しすると on/off がトグルする
     非運転の場合は内部クリーンを２秒長押しすると off になる（これはトグルにならず必ずoff）
     body0
       off : 11 da 27 00 c5 00 20 f7
       on  : 11 da 27 00 c5 00 28 ff

    ** TODO:
     説明書を見ると以下機能があるが、使わないのでいらない
     * P.28 取消を5秒長押し -> さらにエアコンに向けたまま取消を押す -> (ピーとなる) -> エラー・コードがリモコンに表示する
     * P.18
     ** フィルター掃除を2秒長押し + タイマー入を押す -> 自動フィルター掃除がon となる
     ** フィルター掃除を2秒長押し + タイマー切を押す -> 自動フィルター掃除がoff となる

H84,L76,H83,L76,H83,L77,H83,L76,H83,L76,H84,L4748,H652,L321,H83,L239,H83,L77,H83,L76,H83,L76,H84,L238,H83,L76,H84,L76,H83,L76,H75,L76,H83,L238,H84,L76,H83,L238,H84,L238,H84,L76,H83,L239,H83,L238,H84,L238,H84,L238,H84,L238,H84,L75,H84,L76,H83,L239,H83,L76,H83,L76,H84,L76,H83,L76,H84,L76,H83,L76,H83,L77,H83,L76,H83,L76,H84,L76,H85,L236,H84,L76,H83,L239,H83,L76,H83,L77,H83,L76,H83,L239,H83,L239,H83,L76,H83,L76,H84,L76,H86,L72,H84,L76,H83,L76,H83,L68,H83,L76,H83,L76,H83,L77,H83,L76,H83,L76,H84,L76,H83,L239,H83,L76,H83,L76,H84,L238,H84,L238,H83,L239,H83,L76,H84,L238,H84,L238,H83,L239,H83,L239,H83,L6502,H652,L320,H83,L238,H83,L76,H76,L75,H83,L76,H84,L238,H83,L76,H84,L76,H83,L76,H83,L76,H84,L238,H84,L76,H83,L239,H83,L238,H77,L73,H83,L238,H84,L238,H84,L238,H84,L238,H84,L238,H83,L76,H84,L76,H83,L238,H78,L72,H83,L76,H84,L76,H83,L78,H80,L77,H83,L76,H83,L76,H84,L76,H83,L76,H84,L75,H84,L76,H83,L239,H83,L76,H83,L77,H78,L71,H83,L76,H84,L231,H81,L76,H83,L76,H83,L76,H84,L76,H83,L76,H84,L75,H84,L76,H83,L76,H84,L76,H83,L76,H83,L77,H79,L70,H83,L76,H84,L76,H83,L70,H80,L76,H83,L76,H83,L76,H84,L76,H83,L238,H84,L76,H83,L239,H83,L76,H84,L238,H84,L75,H84,L6501,H653,L319,H78,L235,H83,L76,H84,L68,H81,L76,H83,L239,H83,L76,H84,L76,H83,L76,H83,L76,H84,L238,H83,L77,H83,L238,H84,L238,H84,L69,H80,L238,H84,L238,H84,L238,H84,L238,H83,L239,H83,L76,H80,L70,H83,L238,H84,L70,H79,L76,H84,L76,H83,L76,H83,L76,H84,L76,H83,L76,H84,L76,H83,L76,H83,L77,H83,L76,H83,L76,H91,L69,H83,L76,H84,L75,H84,L71,H78,L76,H84,L76,H83,L76,H83,L76,H84,L76,H83,L238,H84,L76,H83,L77,H83,L238,H92,L68,H83,L76,H84,L75,H84,L238,H84,L76,H83,L238,H84,L238,H84,L76,H83,L76,H84,L76,H83,L76,H83,L76,H93,L67,H83,L76,H84,L76,H83,L73,H76,L76,H84,L76,H83,L76,H84,L76,H83,L76,H84,L75,H84,L238,H84,L76,H83,L238,H84,L67,H83,L76,H84,L76,H83,L84,H76,L76,H83,L76,H83,L76,H84,L76,H83,L76,H84,L76,H83,L76,H83,L76,H84,L76,H83,L76,H83,L77,H83,L76,H83,L76,H84,L247,H75,L238,H83,L76,H84,L76,H83,L76,H84,L76,H83,L76,H83,L77,H83,L76,H83,L76,H84,L76,H83,L76,H84,L238,H83,L239,H83,L76,H83,L77,H83,L76,H83,L76,H83,L76,H83,L76,H83,L76,H82,L76,H82,L76,H82,L76,H83,L76,H83,L76,H83,L76,H83,L76,H73,L76,H82,L76,H82,L76,H74,L238,H83,L76,H83,L77,H83,L75,H84,L75,H84,L75,H84,L239,H83,L238,H83,L75,H84,L76,H82,L76,H82,L76,H75,L74,H83,L76,H83,L76,H83,L239,H84,L75,H84,L75,H84,L75,H83,L76,H83,L76,H83,L77,H82,L76,H84,L75,H84,L238,H87,L73,H83,L238,H83,L77,H82,L239,H84,L75,H84,L238,H84,L238,H83,L60000

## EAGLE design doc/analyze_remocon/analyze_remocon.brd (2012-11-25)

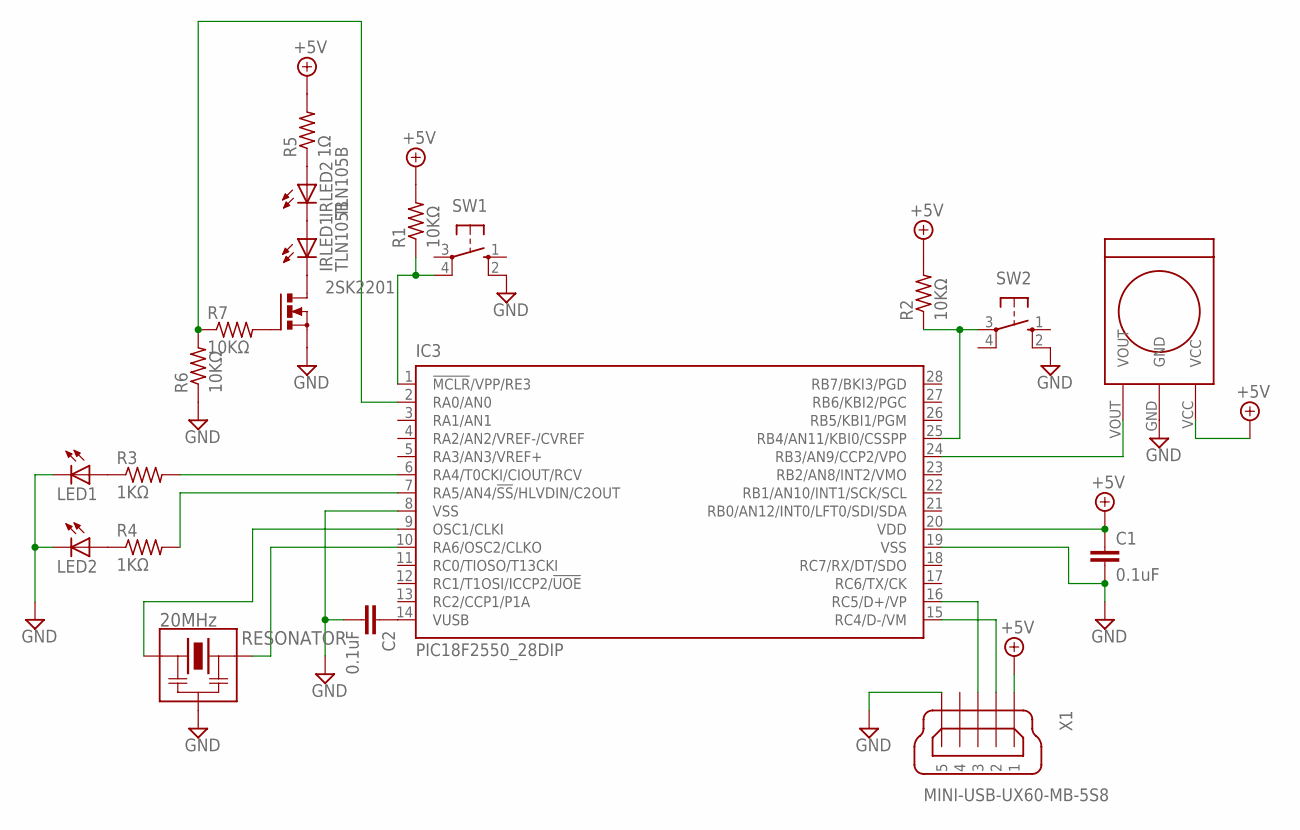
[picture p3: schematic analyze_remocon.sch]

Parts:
2SK2201: BUZ11BV; TO220BV
C1, C2: 0.1uF; C025-024X044
IC3: PIC18F2550_28DIP; DIL28-3
IRLED1, IRLED2: TLN105B; LED3MM
LED1, LED2: LED3MM
PL-IRM2161-C438: IRM2161; PL-IRM2161-C438
R1, R2: 10KΩ; MINI_MELF-0102R
R3, R4: 1KΩ; MINI_MELF-0102R
R5: 1Ω; 0207/7
R6, R7: 10KΩ; 0207/7
RESONATOR: 20MHz; HC-49G
SW1, SW2: 10-XX; B3F-10XX
X1: MINI-USB-UX60-MB-5S8; UX60-MB-5S8

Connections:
20MHZ: IC3.9 (OSC1/CLKI), RESONATOR.P1 (LFT)
BLOCK: C1.1, IC3.20 (VDD), PL-IRM2161-C438.VCC, R1.2, R2.2, R5.2, X1.1
GND: 2SK2201.S, C1.2, C2.2, IC3.8 (VSS), IC3.19 (VSS), LED1.K (C), LED2.K (C), PL-IRM2161-C438.GND, R6.1, RESONATOR.CENT (GND), SW1.2 (S1), SW2.2 (S1), X1.5
unnamed: IC3.15 (RC4/D-/VM), X1.2
unnamed: IC3.16 (RC5/D+/VP), X1.3
unnamed: C2.1, IC3.14 (VUSB)
unnamed: IC3.1 (!MCLR!/VPP/RE3), R1.1, SW1.4 (P1)
unnamed: IC3.25 (RB4/AN11/KBI0/CSSPP), R2.1, SW2.3
unnamed: IC3.10 (RA6/OSC2/CLKO), RESONATOR.P2 (RIT)
unnamed: IC3.6 (RA4/T0CKI/CIOUT/RCV), R3.2
unnamed: LED1.A, R3.1
unnamed: IC3.7 (RA5/AN4/!SS!/HLVDIN/C2OUT), R4.2
unnamed: LED2.A, R4.1
unnamed: IC3.2 (RA0/AN0), R6.2, R7.1
unnamed: IRLED2.A, R5.1
unnamed: IRLED1.A, IRLED2.K (C)
unnamed: 2SK2201.D, IRLED1.K (C)
unnamed: 2SK2201.G, R7.2
unnamed: IC3.24 (RB3/AN9/CCP2/VPO), PL-IRM2161-C438.VOUT

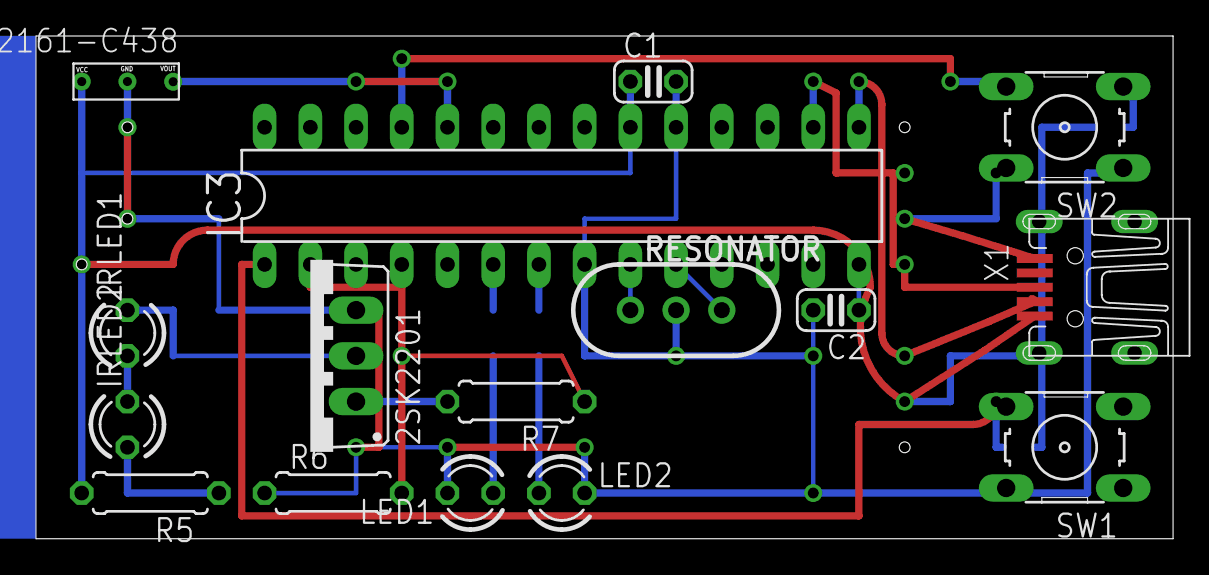
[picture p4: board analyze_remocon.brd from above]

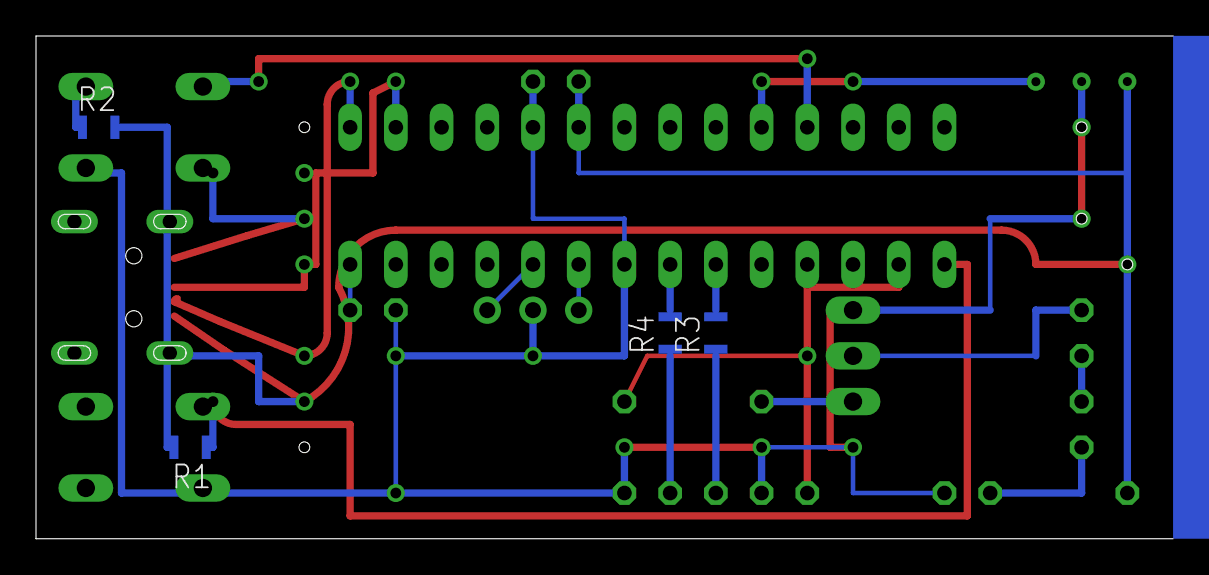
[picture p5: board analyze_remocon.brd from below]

Board: 2 copper layers, 63.2 x 27.9 mm, 20 parts (4 on the bottom side), 19 nets.

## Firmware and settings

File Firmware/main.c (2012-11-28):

/********************************************************************
 FileName:      main.c
 Dependencies:  See INCLUDES section
 Processor:     PIC18, PIC24, dsPIC, and PIC32 USB Microcontrollers
 Hardware:      This demo is natively intended to be used on Microchip USB demo
                boards supported by the MCHPFSUSB stack.  See release notes for
                support matrix.  This demo can be modified for use on other 
                hardware platforms.
 Complier:      Microchip C18 (for PIC18), XC16 (for PIC24/dsPIC), XC32 (for PIC32)
 Company:       Microchip Technology, Inc.

 Software License Agreement:

 The software supplied herewith by Microchip Technology Incorporated
 (the "Company") for its PIC� Microcontroller is intended and
 supplied to you, the Company's customer, for use solely and
 exclusively on Microchip PIC Microcontroller products. The
 software is owned by the Company and/or its supplier, and is
 protected under applicable copyright laws. All rights are reserved.
 Any use in violation of the foregoing restrictions may subject the
 user to criminal sanctions under applicable laws, as well as to
 civil liability for the breach of the terms and conditions of this
 license.

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
********************************************************************
 File Description:

 Change History:
  Rev   Description
  ----  -----------------------------------------
  1.0   Initial release

  2.1   Updated for simplicity and to use common
        coding style

  2.6a  Added button debouncing using Start-of-Frame packets

  2.7   Updated demo to place the PIC24F devices into sleep when the
        USB is in suspend.  

  2.7b  Improvements to USBCBSendResume(), to make it easier to use.
  2.9f  Adding new part support
********************************************************************/

/** INCLUDES *******************************************************/
#include "./USB/usb.h"
#include "./USB/usb_function_cdc.h"
#include <timers.h>
#include <delays.h>

#include "HardwareProfile.h"

/** CONFIGURATION **************************************************/
// Configuration bits for PICDEM FS USB Demo Board (based on PIC18F4550)
#pragma config PLLDIV   = 5         // (20 MHz crystal on PICDEM FS USB board)
#if (USB_SPEED_OPTION == USB_FULL_SPEED)
    #pragma config CPUDIV   = OSC1_PLL2  
#else
    #pragma config CPUDIV   = OSC3_PLL4   
#endif
#pragma config USBDIV   = 2         // Clock source from 96MHz PLL/2
#pragma config FOSC     = HSPLL_HS
#pragma config FCMEN    = OFF
#pragma config IESO     = OFF
#pragma config PWRT     = OFF
#pragma config BOR      = ON
#pragma config BORV     = 3
#pragma config VREGEN   = ON      //USB Voltage Regulator
#pragma config WDT      = OFF
#pragma config WDTPS    = 32768
#pragma config MCLRE    = ON
#pragma config LPT1OSC  = OFF
#pragma config PBADEN   = OFF
//#pragma config CCP2MX   = ON
#pragma config STVREN   = ON
#pragma config LVP      = OFF
//#pragma config ICPRT    = OFF       // Dedicated In-Circuit Debug/Programming
#pragma config XINST    = OFF       // Extended Instruction Set
#pragma config CP0      = OFF
#pragma config CP1      = OFF
//#pragma config CP2      = OFF
//#pragma config CP3      = OFF
#pragma config CPB      = OFF
//#pragma config CPD      = OFF
#pragma config WRT0     = OFF
#pragma config WRT1     = OFF
//#pragma config WRT2     = OFF
//#pragma config WRT3     = OFF
#pragma config WRTB     = OFF       // Boot Block Write Protection
#pragma config WRTC     = OFF
//#pragma config WRTD     = OFF
#pragma config EBTR0    = OFF
#pragma config EBTR1    = OFF
//#pragma config EBTR2    = OFF
//#pragma config EBTR3    = OFF
#pragma config EBTRB    = OFF

/** I N C L U D E S **********************************************************/

#include "GenericTypeDefs.h"
#include "Compiler.h"
#include "usb_config.h"
#include "USB/usb_device.h"
#include "USB/usb.h"
#include "buffer.h"
#include "button.h"

#include "HardwareProfile.h"

#define LED1_TRIS   TRISAbits.TRISA4
#define LED2_TRIS   TRISAbits.TRISA5
#define IR_TRIS     TRISBbits.TRISB3
#define SW_TRIS     TRISBbits.TRISB4
#define IRLED_TRIS  TRISAbits.TRISA0

#define LED1_PORT   PORTAbits.RA4
#define LED2_PORT   PORTAbits.RA5
#define IR_PORT     PORTBbits.RB3
#define SW_PORT     PORTBbits.RB4
#define IRLED_PORT  PORTAbits.RA0

#define SW_BIT		(1<<4)

#define MAX_WAIT_CYCLE 60000

/** V A R I A B L E S ********************************************************/
// 順番重要:先にアドレス順で後の udata から定義するとバンク内にきちんと収まる
//          これを udata の後に書くと収まらなくなる
// http://tylercsf.blog123.fc2.com/blog-entry-189.html

#pragma udata USER_RAM6=0x600
BYTE buff_user1[0x200];

#pragma udata USER_RAM2=0x200
BYTE buff_user2[0x100];

#if defined(__18CXX)
    #pragma udata
#endif

char USB_In_Buffer[64];
char USB_Out_Buffer[64];
BYTE enableReadIR;


/** P R I V A T E  P R O T O T Y P E S ***************************************/
static void InitializeSystem(void);
void ProcessIO(void);
void USBDeviceTasks(void);
void YourHighPriorityISRCode();
void YourLowPriorityISRCode();
void USBCBSendResume(void);
void BlinkUSBStatus(void);
void UserInit(void);
void ButtonProc(void);
void ReadIR(void);
void SendIR(void);
void SendIRImpl(void);
void DelayIRFreqHi(void);
void DelayIRFreqLo(void);
int WaitToReadySerial(void);
void SerialProc(void);
void PutsString(const rom char *str);
void PutsStringCPtr(char *str);
void PrintIRBuffer(const rom char *title);

BYTE ReadBYTEBuffer(WORD pos); // for debug

/** VECTOR REMAPPING ***********************************************/
#if defined(__18CXX)
	//On PIC18 devices, addresses 0x00, 0x08, and 0x18 are used for
	//the reset, high priority interrupt, and low priority interrupt
	//vectors.  However, the current Microchip USB bootloader 
	//examples are intended to occupy addresses 0x00-0x7FF or
	//0x00-0xFFF depending on which bootloader is used.  Therefore,
	//the bootloader code remaps these vectors to new locations
	//as indicated below.  This remapping is only necessary if you
	//wish to program the hex file generated from this project with
	//the USB bootloader.  If no bootloader is used, edit the
	//usb_config.h file and comment out the following defines:
	//#define PROGRAMMABLE_WITH_USB_HID_BOOTLOADER
	//#define PROGRAMMABLE_WITH_USB_LEGACY_CUSTOM_CLASS_BOOTLOADER
	
	#if defined(PROGRAMMABLE_WITH_USB_HID_BOOTLOADER)
		#define REMAPPED_RESET_VECTOR_ADDRESS			0x1000
		#define REMAPPED_HIGH_INTERRUPT_VECTOR_ADDRESS	0x1008
		#define REMAPPED_LOW_INTERRUPT_VECTOR_ADDRESS	0x1018
	#elif defined(PROGRAMMABLE_WITH_USB_MCHPUSB_BOOTLOADER)	
		#define REMAPPED_RESET_VECTOR_ADDRESS			0x800
		#define REMAPPED_HIGH_INTERRUPT_VECTOR_ADDRESS	0x808
		#define REMAPPED_LOW_INTERRUPT_VECTOR_ADDRESS	0x818
	#else	
		#define REMAPPED_RESET_VECTOR_ADDRESS			0x00
		#define REMAPPED_HIGH_INTERRUPT_VECTOR_ADDRESS	0x08
		#define REMAPPED_LOW_INTERRUPT_VECTOR_ADDRESS	0x18
	#endif
	
	#if defined(PROGRAMMABLE_WITH_USB_HID_BOOTLOADER)||defined(PROGRAMMABLE_WITH_USB_MCHPUSB_BOOTLOADER)
	extern void _startup (void);        // See c018i.c in your C18 compiler dir
	#pragma code REMAPPED_RESET_VECTOR = REMAPPED_RESET_VECTOR_ADDRESS
	void _reset (void)
	{
	    _asm goto _startup _endasm
	}
	#endif
	#pragma code REMAPPED_HIGH_INTERRUPT_VECTOR = REMAPPED_HIGH_INTERRUPT_VECTOR_ADDRESS
	void Remapped_High_ISR (void)
	{
	     _asm goto YourHighPriorityISRCode _endasm
	}
	#pragma code REMAPPED_LOW_INTERRUPT_VECTOR = REMAPPED_LOW_INTERRUPT_VECTOR_ADDRESS
	void Remapped_Low_ISR (void)
	{
	     _asm goto YourLowPriorityISRCode _endasm
	}
	
	#if defined(PROGRAMMABLE_WITH_USB_HID_BOOTLOADER)||defined(PROGRAMMABLE_WITH_USB_MCHPUSB_BOOTLOADER)
	//Note: If this project is built while one of the bootloaders has
	//been defined, but then the output hex file is not programmed with
	//the bootloader, addresses 0x08 and 0x18 would end up programmed with 0xFFFF.
	//As a result, if an actual interrupt was enabled and occured, the PC would jump
	//to 0x08 (or 0x18) and would begin executing "0xFFFF" (unprogrammed space).  This
	//executes as nop instructions, but the PC would eventually reach the REMAPPED_RESET_VECTOR_ADDRESS
	//(0x1000 or 0x800, depending upon bootloader), and would execute the "goto _startup".  This
	//would effective reset the application.

	//To fix this situation, we should always deliberately place a
	//"goto REMAPPED_HIGH_INTERRUPT_VECTOR_ADDRESS" at address 0x08, and a
	//"goto REMAPPED_LOW_INTERRUPT_VECTOR_ADDRESS" at address 0x18.  When the output
	//hex file of this project is programmed with the bootloader, these sections do not
	//get bootloaded (as they overlap the bootloader space).  If the output hex file is not
	//programmed using the bootloader, then the below goto instructions do get programmed,
	//and the hex file still works like normal.  The below section is only required to fix this
	//scenario.
	#pragma code HIGH_INTERRUPT_VECTOR = 0x08
	void High_ISR (void)
	{
	     _asm goto REMAPPED_HIGH_INTERRUPT_VECTOR_ADDRESS _endasm
	}
	#pragma code LOW_INTERRUPT_VECTOR = 0x18
	void Low_ISR (void)
	{
	     _asm goto REMAPPED_LOW_INTERRUPT_VECTOR_ADDRESS _endasm
	}
	#endif	//end of "#if defined(PROGRAMMABLE_WITH_USB_HID_BOOTLOADER)||defined(PROGRAMMABLE_WITH_USB_LEGACY_CUSTOM_CLASS_BOOTLOADER)"

	#pragma code

	//These are your actual interrupt handling routines.
	#pragma interrupt YourHighPriorityISRCode
	void YourHighPriorityISRCode()
	{
		//INTCONbits.GIEH = 0;
		//INTCONbits.GIEH = 1;

		//Check which interrupt flag caused the interrupt.
		//Service the interrupt
		//Clear the interrupt flag
		//Etc.
        #if defined(USB_INTERRUPT)
	        USBDeviceTasks();
        #endif
	
	}	//This return will be a "retfie fast", since this is in a #pragma interrupt section 
	#pragma interruptlow YourLowPriorityISRCode
	void YourLowPriorityISRCode()
	{
		//Check which interrupt flag caused the interrupt.
		//Service the interrupt
		//Clear the interrupt flag
		//Etc.
	
	}	//This return will be a "retfie", since this is in a #pragma interruptlow section 



/** DECLARATIONS ***************************************************/
#if defined(__18CXX)
    #pragma code
#endif

/******************************************************************************
 * Function:        void main(void)
 *
 * PreCondition:    None
 *
 * Input:           None
 *
 * Output:          None
 *
 * Side Effects:    None
 *
 * Overview:        Main program entry point.
 *
 * Note:            None
 *****************************************************************************/
#if defined(__18CXX)
void main(void)
#else
int main(void)
#endif
{   
    InitializeSystem();

    while(1)
    {
        #if defined(USB_INTERRUPT)
            if(USB_BUS_SENSE && (USBGetDeviceState() == DETACHED_STATE))
            {
                USBDeviceAttach();
            }
        #endif

        #if defined(USB_POLLING)
		// Check bus status and service USB interrupts.
        USBDeviceTasks(); // Interrupt or polling method.  If using polling, must call
        				  // this function periodically.  This function will take care
        				  // of processing and responding to SETUP transactions 
        				  // (such as during the enumeration process when you first
        				  // plug in).  USB hosts require that USB devices should accept
        				  // and process SETUP packets in a timely fashion.  Therefore,
        				  // when using polling, this function should be called 
        				  // regularly (such as once every 1.8ms or faster** [see 
        				  // inline code comments in usb_device.c for explanation when
        				  // "or faster" applies])  In most cases, the USBDeviceTasks() 
        				  // function does not take very long to execute (ex: <100 
        				  // instruction cycles) before it returns.
        #endif
    				  

		// Application-specific tasks.
		// Application related code may be added here, or in the ProcessIO() function.
        ProcessIO();        
    }//end while
}//end main


/********************************************************************
 * Function:        static void InitializeSystem(void)
 *
 * PreCondition:    None
 *
 * Input:           None
 *
 * Output:          None
 *
 * Side Effects:    None
 *
 * Overview:        InitializeSystem is a centralize initialization
 *                  routine. All required USB initialization routines
 *                  are called from here.
 *
 *                  User application initialization routine should
 *                  also be called from here.                  
 *
 * Note:            None
 *******************************************************************/
static void InitializeSystem(void)
{
    ADCON1 |= 0x0F;                 // Default all pins to digital
    UserInit();
    USBDeviceInit();	//usb_device.c.  Initializes USB module SFRs and firmware
    					//variables to known states.
}//end InitializeSystem



/******************************************************************************
 * Function:        void UserInit(void)
 *
 * PreCondition:    None
 *
 * Input:           None
 *
 * Output:          None
 *
 * Side Effects:    None
 *
 * Overview:        This routine should take care of all of the demo code
 *                  initialization that is required.
 *
 * Note:            
 *
 *****************************************************************************/
void UserInit(void)
{
	// initialize
	LED1_TRIS = 0; // LED1 output
	LED2_TRIS = 0; // LED2 output
	IR_TRIS   = 1; // IR input
	SW_TRIS   = 1; // SW input
	IRLED_TRIS= 0; // IRLED input
	LED1_PORT = 0;
	LED2_PORT = 0;
	IRLED_PORT= 0;
	//IRLED_PORT= 1;

	// timer0 48MHz/4=12MHz => 0.08333[us/cycle] => *  2 =>  0.16666us -> *65536 = 10.923ms
	// timer0 48MHz/4=12MHz => 0.08333[us/cycle] => *  4 =>  0.33333us -> *65536 = 21.845ms
	// timer0 48MHz/4=12MHz => 0.08333[us/cycle] => *  8 =>  0.66666us -> *65536 = 43.69ms
	// timer0 48MHz/4=12MHz => 0.08333[us/cycle] => * 16 =>  1.33333us -> *65536 = 87.381ms
	// timer0 48MHz/4=12MHz => 0.08333[us/cycle] => * 32 =>  2.66666us -> *65536 = 174.76ms
	// timer0 48MHz/4=12MHz => 0.08333[us/cycle] => * 64 =>  5.33333us -> *65536 = 349.5ms
	// timer0 48MHz/4=12MHz => 0.08333[us/cycle] => *128 => 10.66666us -> *65536 = 699ms
	// timer0 48MHz/4=12MHz => 0.08333[us/cycle] => *256 => 21.33333us -> *65536 = 1398ms
	T0CON = TIMER_INT_ON &
		    T0_16BIT &
		    T0_SOURCE_INT &
		    T0_EDGE_RISE & // なんでもいい
		    T0_PS_1_64;

	// max 43.69[ms]
	T1CON = TIMER_INT_ON &
		    T1_16BIT_RW &
		    T1_SOURCE_INT &
		    T1_PS_1_8;


	// initilize other variables
    InitBuffer();
    AddBuffer(buff_user1, sizeof(buff_user1));
    AddBuffer(buff_user2, sizeof(buff_user2));
	ButtonInit(SW_BIT);
	enableReadIR = 1;
}//end UserInit

/********************************************************************
 * Function:        void ProcessIO(void)
 *
 * PreCondition:    None
 *
 * Input:           None
 *
 * Output:          None
 *
 * Side Effects:    None
 *
 * Overview:        This function is a place holder for other user
 *                  routines. It is a mixture of both USB and
 *                  non-USB tasks.
 *
 * Note:            None
 *******************************************************************/
void ProcessIO(void)
{   
	LED1_PORT = 0;
	IRLED_PORT = 0;

	//IRLED_PORT = 1;
	ButtonProc();
	ReadIR();
	SendIR();

    SerialProc();
    CDCTxService();
}

void SerialProc(void)
{
    BYTE numBytesRead;
	BYTE i;
    char buff[10];
    char *buffPtr;
    char *usbPtr;
    char state; // 0:readed ',' 1:readed number
	BYTE exit;
	WORD byteOrWord; // 0:未設定
	WORD pos;
    WORD v;
    WORD bpos;

    // User Application USB tasks
    if((USBDeviceState < CONFIGURED_STATE)||(USBSuspendControl==1))
        return;

	if(!USBUSARTIsTxTrfReady())
        return;

    bpos = 0;
    numBytesRead = getsUSBUSART(USB_Out_Buffer,64);
	if(numBytesRead == 0)
        return;

    state = 0;
    buffPtr = buff;
    usbPtr = USB_Out_Buffer;
	pos = 0;
	byteOrWord = 0;
	exit = 0;
 loop:
	for(i=0;i<numBytesRead;i++) {
        if (usbPtr[i]=='\r' || usbPtr[i]=='\n'){
            if (pos>0) {
                if (buffPtr==buff) {
                    sprintf(USB_In_Buffer,
                            (far rom char*)"parse error. need number. [%d,%c]\r\n",
                            bpos+i,usbPtr[i]);
                    PutsStringCPtr(USB_In_Buffer);
                    return;
                }
                *buffPtr++ = '\0';
                v = atoi(buff);
                exit += WriteBuffer(v,&pos,&byteOrWord);
                buffPtr = buff;

                WriteEOF(pos);
                PrintIRBuffer("echo,");
                SendIRImpl();
            }
            return;
        } else if (state==0) {
            if(usbPtr[i] != 'H' && usbPtr[i] != 'L') {
                sprintf(USB_In_Buffer,
                        (far rom char*)"parse error. need 'H' or 'L'. [%d,%c]\r\n",
                        bpos+i,usbPtr[i]);
                PutsStringCPtr(USB_In_Buffer);

                WriteEOF(pos);
                PrintIRBuffer("echo,");
                return;
            }
            state = 1;
        } else if (state==1) {
            if (usbPtr[i] == ',') {
                state = 0;
                if (buffPtr==buff) {
                    sprintf(USB_In_Buffer,
                            (far rom char*)"parse error. need number. [%d,%c]\r\n",
                            bpos+i,usbPtr[i]);
                    PutsStringCPtr(USB_In_Buffer);
                    WriteEOF(pos);
                    PrintIRBuffer("echo,");
                    return;
                }
                *buffPtr++ = '\0';
                v = atoi(buff);
                exit += WriteBuffer(v,&pos,&byteOrWord);
                buffPtr = buff;
            } else if ('0' <= usbPtr[i] && usbPtr[i] <= '9') {
                *buffPtr++ = usbPtr[i];
            } else {
                sprintf(USB_In_Buffer,
                        (far rom char*)"parse error. need ',' or number. [%d,%c]\r\n",
                        bpos+i,usbPtr[i]);
                PutsStringCPtr(USB_In_Buffer);
                WriteEOF(pos);
                PrintIRBuffer("echo,");
                return;
            }
        }
    }
    bpos += numBytesRead;
	numBytesRead = getsUSBUSART(USB_Out_Buffer,64);
    goto loop;
}


void ButtonProc(void)
{
	ButtonProcEveryMainLoop(PORTB);
	if (ButtonLongDownState() & SW_BIT)
		enableReadIR = !enableReadIR ;

	LED2_PORT = enableReadIR;
}

void ReadIR(void)
{
	WORD t;
	BYTE hilo;
	BYTE exit;
	WORD byteOrWord; // 0:未設定
	WORD pos;

	if (enableReadIR==0)
		return;

	if (IR_PORT == 1)
		return;

	// なにか信号があった

	WriteTimer0(0);
	INTCONbits.TMR0IF = 0;
	hilo = 0;

	pos = 0;
	byteOrWord = 0;
	exit = 0;
	while (exit==0) {
		LED1_PORT = !hilo;
		do {
			t = ReadTimer0();
			if (INTCONbits.TMR0IF || (t > MAX_WAIT_CYCLE)) {
				t = MAX_WAIT_CYCLE;
				INTCONbits.TMR0IF = 0;
				exit=1;
				break;
			}
		} while (IR_PORT == hilo);
		WriteTimer0(0);
		exit += WriteBuffer(t,&pos,&byteOrWord);
		hilo = !hilo;
	}
	LED1_PORT = 0;
    WriteEOF(pos);

	if (!WaitToReadySerial())
		return;
    PrintIRBuffer("received,");
}

void PrintIRBuffer(const rom char *title)
{
	WORD t;
	BYTE hilo;
	WORD byteOrWord; // 0:未設定
	WORD pos;
	char separator[2] = {'\0','\0'};

	PutsString("");  // なぜかこの出力がないと１発目が化ける

	PutsString(title);

	hilo = 1;
	pos = 0;
	byteOrWord = 0;
	while (1) {
		if (!WaitToReadySerial()) return;
		t = ReadBuffer(&pos,&byteOrWord);
		if (t==BUFF_EOF)
			break;
		sprintf(USB_In_Buffer, (far rom char*)"%s%c%u",
				separator,
				hilo ? 'H' : 'L',
				t);
		putsUSBUSART(USB_In_Buffer);
		hilo=!hilo;
		separator[0] = ',';
	}
	if (!WaitToReadySerial()) return;
	sprintf(USB_In_Buffer, (far rom char*)"\r\n");
	putsUSBUSART(USB_In_Buffer);
	if (!WaitToReadySerial()) return;
}

void SendIR(void)
{
	if ((ButtonUpState() & SW_BIT)==0)
		return;
    SendIRImpl();
}

void SendIRImpl(void)
{
	WORD t,wait;
	BYTE hilo;
	WORD pos;
	WORD byteOrWord; // 0:未設定

	WriteTimer0(0);
	INTCONbits.TMR0IF = 0;

	hilo = 1;
	pos = 0;
	byteOrWord = 0;
	while (1) {
		wait = ReadBuffer(&pos,&byteOrWord);
		if (wait==BUFF_EOF)
            break;
		if (wait==MAX_WAIT_CYCLE)
			break;
		do {
			LED1_PORT = hilo;
			//IRLED_PORT = !hilo;
			IRLED_PORT = hilo;
			DelayIRFreqHi();
			t = ReadTimer0();
			if (t >= wait)
				break;
			LED1_PORT = 0;
			//IRLED_PORT = 1;
			IRLED_PORT = 0;
			DelayIRFreqLo();
			t = ReadTimer0();
		} while(t < wait);

		WriteTimer0(0);
		hilo = !hilo;
		LED1_PORT = hilo;
		//IRLED_PORT = !hilo;
		IRLED_PORT = hilo;
	}

	// wait 10msec [1cycle==0.083333333us]
    Delay10KTCYx(120);
	LED1_PORT = 0;
	//IRLED_PORT = 1;
	IRLED_PORT = 0;

    PutsString("sended ir\r\n");

	LED1_PORT = 0;
	//IRLED_PORT = 1;
	IRLED_PORT = 0;
}

void PutsString(const rom char *str)
{
	if (!WaitToReadySerial()) return;
	strcpypgm2ram(USB_In_Buffer, (const far rom char*)str);
	putsUSBUSART(USB_In_Buffer);
	if (!WaitToReadySerial()) return;
}

void PutsStringCPtr(char *str)
{
	if (!WaitToReadySerial()) return;
	putsUSBUSART(str);
	if (!WaitToReadySerial()) return;
}


// 38KHz のデューティー比 33% の HI で待つ
// HI:105.263157894737[cycle] == 8.77192982456142[us]
// 38KHz のデューティー比 50% の 場合
// HI:157.894736842105[cycle] == 13.1578947368421[us]
void DelayIRFreqHi(void)
{
	// duty 1/3
	Delay10TCYx(10);
	Delay1TCY();
	Delay1TCY();
	Delay1TCY();
	Delay1TCY();
	Delay1TCY();

	// duty 1/2
	//Delay10TCYx(15);
	//Delay1TCY();
	//Delay1TCY();
	//Delay1TCY();
	//Delay1TCY();
	//Delay1TCY();
	//Delay1TCY();
	//Delay1TCY();
}

// 38KHz のデューティー比 33% の LO で待つ
// LO:210.526315789474[cycle] == 17.5438596491228[us]
// 38KHz のデューティー比 50% の 場合
// LO:157.894736842105[cycle] == 13.1578947368421[us]
void DelayIRFreqLo(void)
{
	// duty 1/3
	Delay10TCYx(21);
	Delay1TCY();

	// duty 1/2
	//Delay10TCYx(15);
	//Delay1TCY();
	//Delay1TCY();
	//Delay1TCY();
	//Delay1TCY();
	//Delay1TCY();
	//Delay1TCY();
	//Delay1TCY();
}
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

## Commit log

2012-10-10 add timer and debug codes.
2012-10-14 refined timer
2012-10-23 add eagle document
    [analyze_remocon.sch, untitled.sch]
2012-10-25 change correct hi and lo frequency
    [main.c]
2012-10-25 add one LED and change IO port
2012-10-26 add button implementation
2012-11-18 update circuit diagram documents
    [analyze_remocon.brd, analyze_remocon.sch, untitled.sch]
2012-11-20 add circuit diagram image
2012-11-25 update circuit diagram documents. fix D+ D- line.
    [analyze_remocon.brd, analyze_remocon.sch]
2012-11-25 add serial ruby interface. and fix to receive serial data problem.
    [main.c]
2012-11-26 fix mojibake at first time.
    [main.c]
2012-12-05 change format name to upper case
2013-06-02 add schematic image
2013-07-16 write button's specification and few text modified
